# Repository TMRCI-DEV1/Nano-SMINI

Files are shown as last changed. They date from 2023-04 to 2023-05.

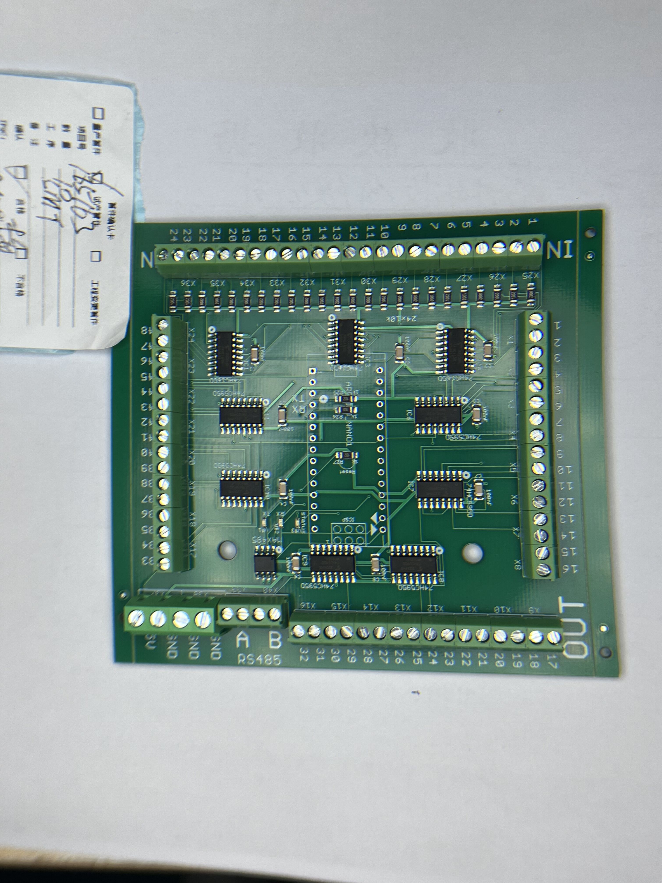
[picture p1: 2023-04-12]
KiCad/3D_Models/185163-1.jpg

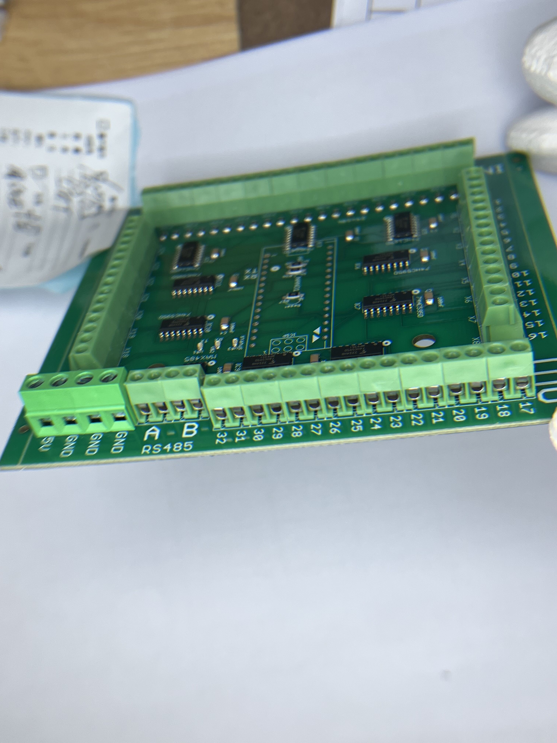
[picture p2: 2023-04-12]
KiCad/3D_Models/185163-2.jpg

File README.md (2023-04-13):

# Nano-SMINI
Arduino Nano-based CMRI SMINI
capture-2023-03-27T16_43_42 577Z

Shield: [][cc-by-sa]

This work is licensed under a
[Creative Commons Attribution-ShareAlike 4.0 International License][cc-by-sa].

[][cc-by-sa]

[cc-by-sa]: http://creativecommons.org/licenses/by-sa/4.0/
[cc-by-sa-image]: https://licensebuttons.net/l/by-sa/4.0/88x31.png
[cc-by-sa-shield]: https://img.shields.io/badge/License-CC%20BY--SA%204.0-lightgrey.svg

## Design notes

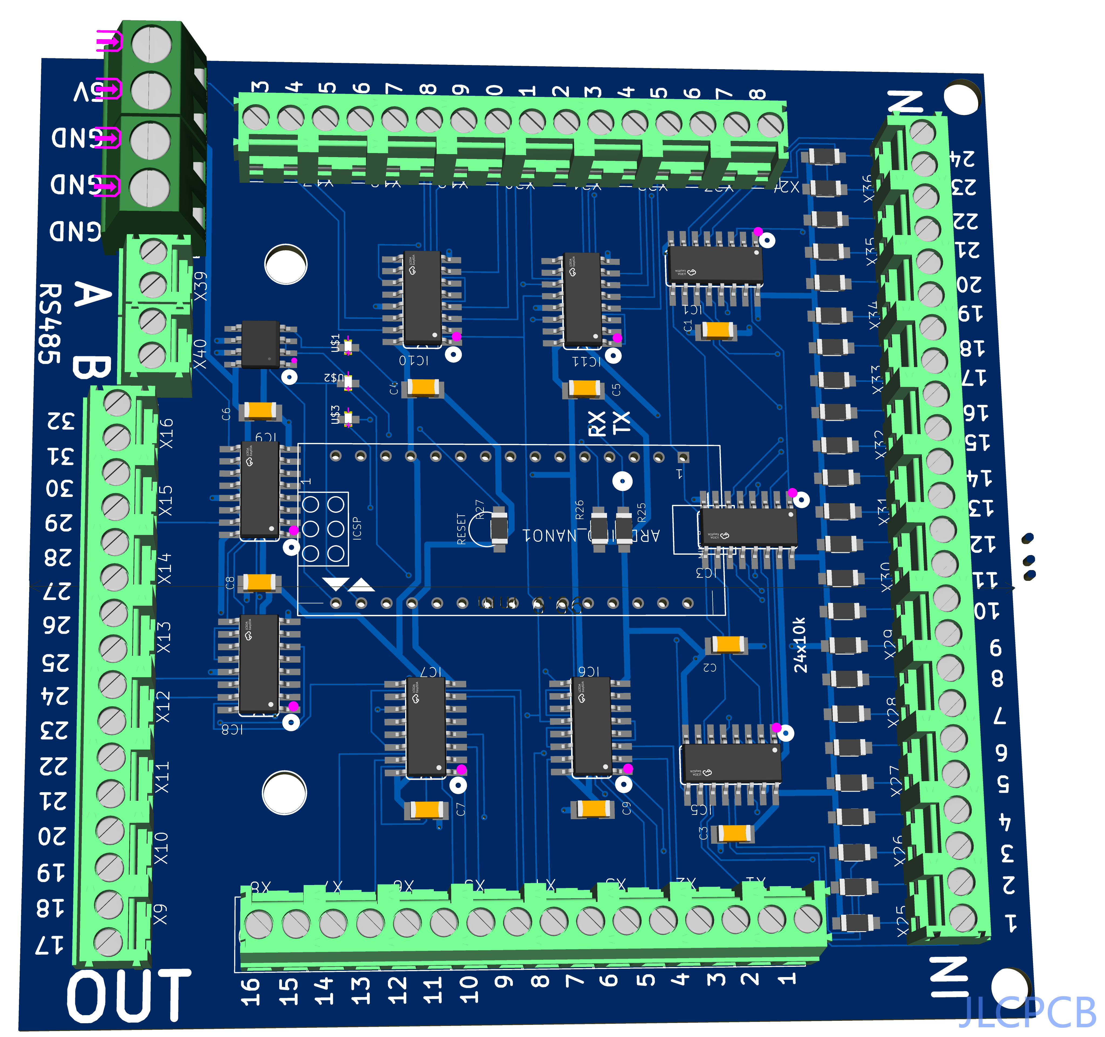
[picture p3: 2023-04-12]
KiCad/3D_Models/capture-2023-03-27T16_43_42.577Z.png

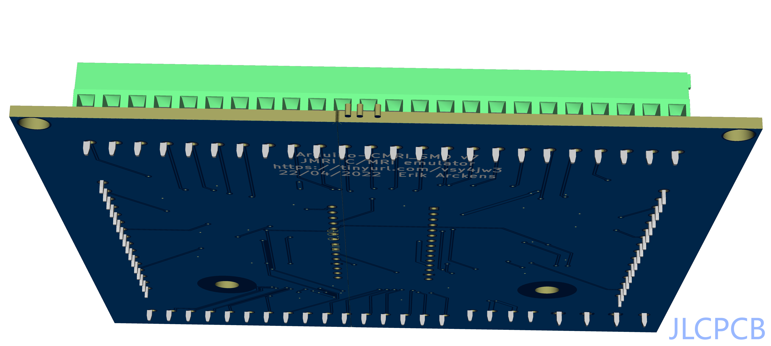
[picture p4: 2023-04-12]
KiCad/3D_Models/capture-2023-03-27T16_43_13.949Z.png

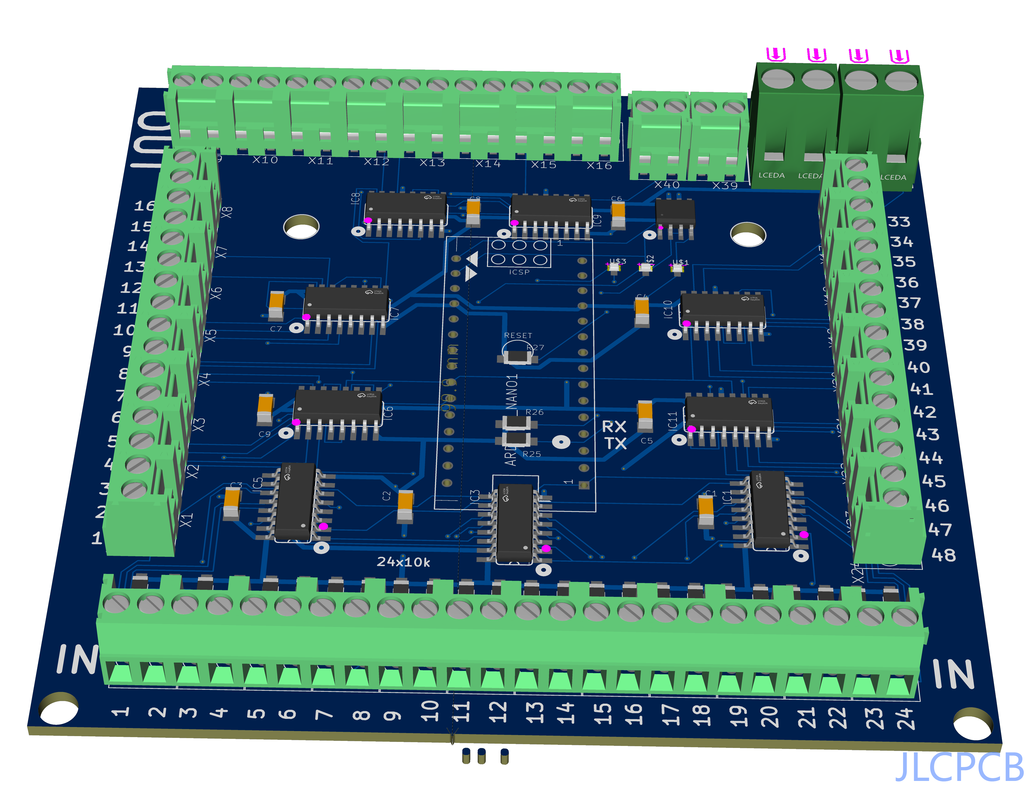
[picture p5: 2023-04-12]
KiCad/3D_Models/capture-2023-03-27T16_43_01.188Z.png

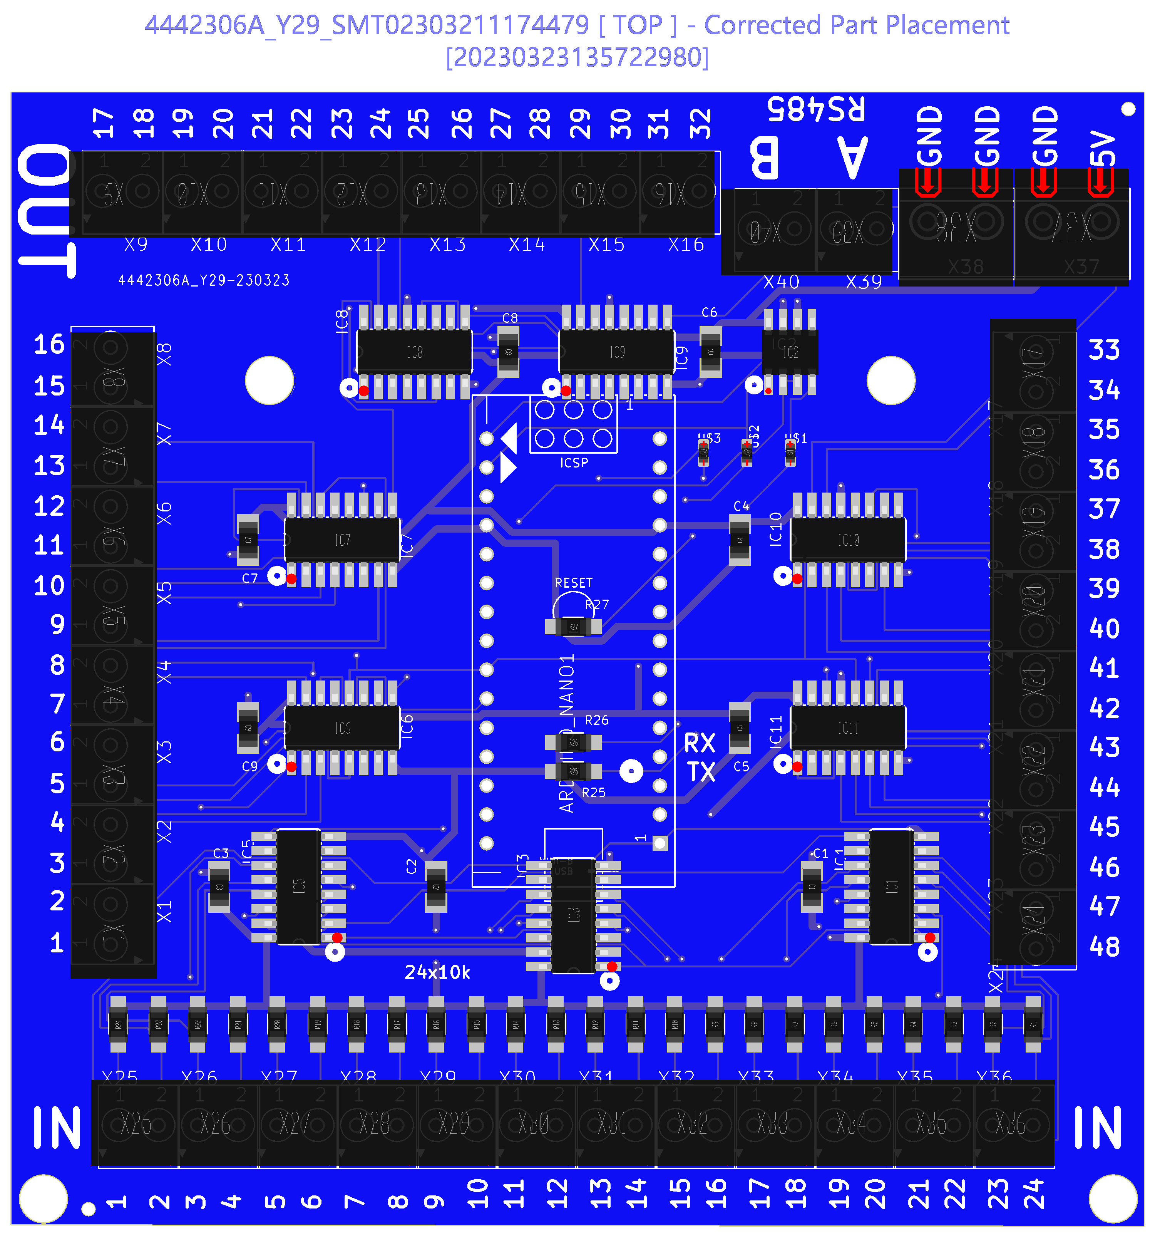
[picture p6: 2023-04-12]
KiCad/3D_Models/Produce_DanZhi.SMT_Snapshot.Top.4442306A_Y29.SMT02303211174479.png

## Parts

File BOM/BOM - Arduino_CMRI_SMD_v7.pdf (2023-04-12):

Designators | Value | Footprint | Manufacturer Part Number | Quantity
C1, C2, C3, C4, C5, C6, C7, C8, C9 | 100nF | 1206 | CL31B104KBCNNNC | 9
R1, R2, R3, R4, R5, R6, R7, R8, R9, R10, R11, R12, R13, R14,
R15, R16, R17, R18, R19, R20, R21, R22, R23, R24 | 10k | 1206 | 1206W4F1002T5E | 24
R25, R26, R27 | 1k | 1206 | 1206W4F1001T5 | 3

X1, X2, X3, X4, X5, X6, X7, X8, X9, X10, X11, X12, X13, X14,
X15, X16, X17, X18, X19, X20, X21, X22, X23, X24, X25, X26,
X27, X28, X29, X30, X31, X32, X33, X34, X35, X36, X39, X40 TERMINAL_7.5X7.3MM_TM | TERMINAL_7.5X7.3MM_TM | KF350-3.5-2P | 38
X37, X38 | TERMINAL_10.16X8.1MM_TM | TERMINAL_10.16X8.1MM_TM WJ128V-5.0-2P | 2
IC6, IC7, IC8, IC9, IC10, IC11 | 74HC595D | SOP16_150MIL | 74HC595D | 6
IC1, IC3, IC5 | 74HC165D, 653 | SOIC16_150MIL | 74HC165D,653 | 3
H1, H2 | MOUNT-HOLE4.1 | 4,1 | 2 | DNP
ARDUINO_NANO1 | ARDUINO_NANO_HEADERS | 15Fx1-254mm | 2 | DNP | 15Fx1-254mm (https://www.electromaker.io/shop/product/254mm-01-15-pin-female-header)
IC2 | MAX485 | SOP8 | MAX485ED | 1
U$1 | TX，CHIPLED_0603, blue | 0603 | LTST-C190TBKT | 1
U$2 | RX，CHIPLED_0603, red | 0603 | LTST-C190KRKT | 1
U$3 | status，CHIPLED_0603, yellow | 0603 | LTST-C190KSKT | 1

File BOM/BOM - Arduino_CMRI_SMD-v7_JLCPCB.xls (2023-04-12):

Comment | Designator | Footprint | JLCPCB Part #
status，CHIPLED_0603,yellow | U$3 | 0603 | C125095
100nF | C1,C2,C3,C4,C5,C6,C7,C8,C9 | 1206 | C24497
MAX485，SO08 | IC2 | SOP8 | C481667
10k | R1,R2,R3,R4,R5,R6,R7,R8,R9,R10,R11,R12,R13,R14,R15,R16,R17,R18,R19,R20,R21,R22,R23,R24 | 1206 | C17902
TERMINAL_7.5X7.3MM_TM | X1,X2,X3,X4,X5,X6,X7,X8,X9,X10,X11,X12,X13,X14,X15,X16,X17,X18,X19,X20,X21,X22,X23,X24,X25,X26,X27,X28,X29,X30,X31,X32,X33,X34,X35,X36,X39,X40 | TERMINAL_7.5X7.3MM_TM | C474892
74HC165D | IC1,IC3,IC5 | SOIC16_150MIL | C5613
RX，CHIPLED_0603,red | U$2 | 0603 | C94869
1k | R25,R26,R27 | 1206 | C4410
TX，CHIPLED_0603，blue | U$1 | 0603 | C125096
74HC595D | IC6,IC7,IC8,IC9,IC10,IC11 | SOP16_150MIL | C431479
TERMINAL_10.16X8.1MM_TM | X37,X38 | TERMINAL_10.16X8.1MM_TM | C8269

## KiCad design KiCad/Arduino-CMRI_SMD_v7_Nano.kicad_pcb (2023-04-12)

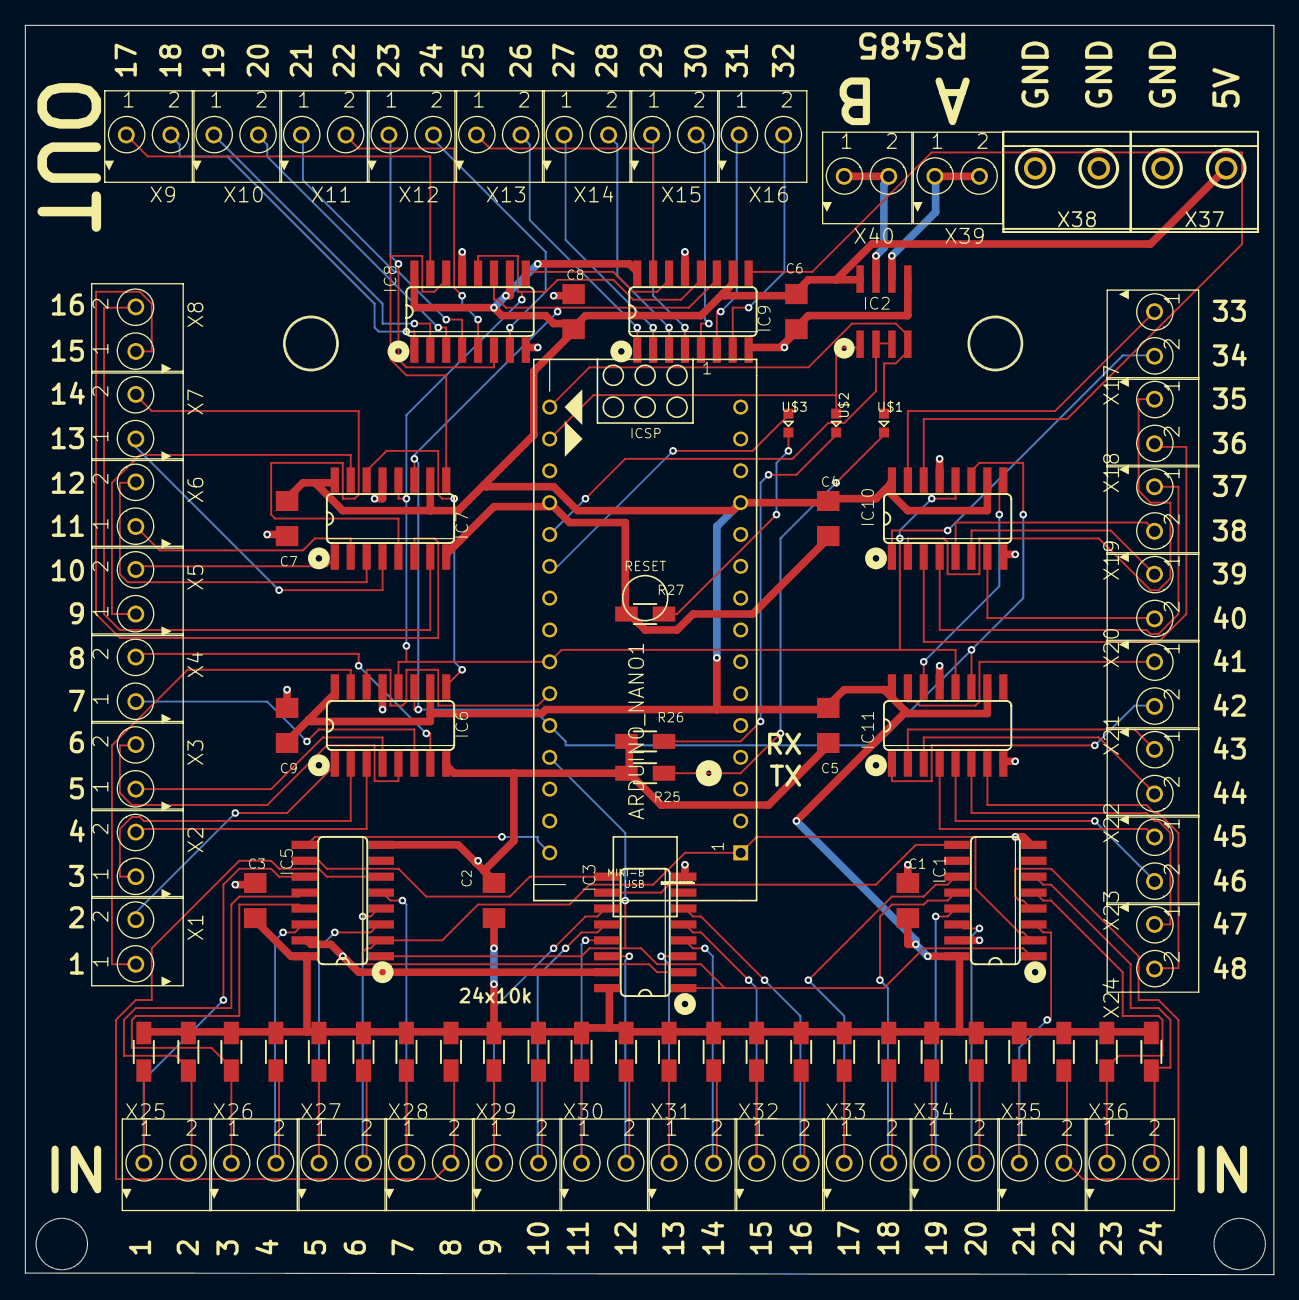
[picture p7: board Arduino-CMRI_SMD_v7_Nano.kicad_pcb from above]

Board: 2 copper layers, 99.6 x 99.7 mm, 92 parts (0 on the bottom side), 96 nets.

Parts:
ARDUINO_NANO1: ARDUINO_NANO
C1, C2, C3, C4, C5, C6, C7, C8, C9: 100nF; 1206
H1, H2: MOUNT-HOLE4.1; 4,1
IC1, IC3, IC5: 74HC165D; SO16
IC2: MAX485; SO08
IC6, IC7, IC8, IC9, IC10, IC11: 74HC595D; SO16
R1, R2, R3, R4, R5, R6, R7, R8, R9, R10, R11, R12, R13, R14, R15, R16, R17, R18, R19, R20, R21, R22, R23, R24: 10k; R1206W
R25, R26, R27: 1k; R1206W
U$1: TX; CHIPLED_0603
U$2: RX; CHIPLED_0603
U$3: status; CHIPLED_0603
X1, X2, X3, X4, X5, X6, X7, X8, X9, X10, X11, X12, X13, X14, X15, X16, X17, X18, X19, X20, X21, X22, X23, X24, X25, X26, X27, X28, X29, X30, X31, X32, X33, X34, X35, X36, X39, X40: TERMINAL_2P_3,5MM_V2; TERMINAL_2P_3,5MM
X37, X38: W237-132

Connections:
A: IC2.6, X39.P$1, X39.P$2
B: IC2.7, X40.P$1, X40.P$2
D2: ARDUINO_NANO1.20, IC2.2, IC2.3
D3: ARDUINO_NANO1.21, U$3.A
D6: ARDUINO_NANO1.24, IC6.12, IC7.12, IC8.12, IC9.12, IC10.12, IC11.12
D7: ARDUINO_NANO1.25, IC6.14
D8: ARDUINO_NANO1.26, IC6.11, IC7.11, IC8.11, IC9.11, IC10.11, IC11.11
D9: ARDUINO_NANO1.27, IC1.1, IC3.1, IC5.1
D12: ARDUINO_NANO1.30, IC5.9
D13: ARDUINO_NANO1.1, IC1.2, IC3.2, IC5.2
GND: ARDUINO_NANO1.14, ARDUINO_NANO1.19, C1.1, C2.1, C3.1, C4.1, C5.1, C6.1, C7.1, C8.1, C9.1, IC1.8, IC1.15, IC2.5, IC3.8, IC3.15, IC5.8, IC5.15, IC6.8, IC6.13, IC7.8, IC7.13, IC8.8, IC8.13, IC9.8, IC9.13, IC10.8, IC10.13, IC11.8, IC11.13, R25.1, R26.1, R27.1, X37.2, X38.1, X38.2
unnamed: IC5.11, R24.1, X25.P$1
unnamed: IC1.9, IC3.10
unnamed: IC5.12, R23.1, X25.P$2
unnamed: IC3.9, IC5.10
unnamed: IC5.13, R22.1, X26.P$1
unnamed: IC6.9, IC7.14
unnamed: IC5.14, R21.1, X26.P$2
unnamed: IC9.9, IC10.14
unnamed: IC5.3, R20.1, X27.P$1
unnamed: IC7.9, IC8.14
unnamed: IC5.4, R19.1, X27.P$2
unnamed: IC10.9, IC11.14
unnamed: IC5.5, R18.1, X28.P$1
unnamed: IC6.15, X1.P$1
unnamed: IC5.6, R17.1, X28.P$2
unnamed: IC6.1, X1.P$2
unnamed: R25.2, U$1.C
unnamed: IC6.2, X2.P$1
unnamed: IC3.11, R16.1, X29.P$1
unnamed: IC6.3, X2.P$2
unnamed: IC3.12, R15.1, X29.P$2
unnamed: IC6.4, X3.P$1
unnamed: IC3.13, R14.1, X30.P$1
unnamed: IC6.5, X3.P$2
unnamed: IC3.14, R13.1, X30.P$2
unnamed: IC6.6, X4.P$1
unnamed: IC3.3, R12.1, X31.P$1
unnamed: IC6.7, X4.P$2
unnamed: IC3.4, R11.1, X31.P$2
unnamed: IC7.15, X5.P$1
unnamed: IC3.5, R10.1, X32.P$1
unnamed: IC7.1, X5.P$2
unnamed: IC3.6, R9.1, X32.P$2
unnamed: IC7.2, X6.P$1
unnamed: IC1.11, R8.1, X33.P$1
unnamed: IC7.3, X6.P$2
unnamed: IC1.12, R7.1, X33.P$2
unnamed: IC7.4, X7.P$1
unnamed: IC1.13, R6.1, X34.P$1
unnamed: IC7.5, X7.P$2
unnamed: IC1.14, R5.1, X34.P$2
unnamed: IC7.6, X8.P$1
unnamed: IC1.3, R4.1, X35.P$1
unnamed: IC7.7, X8.P$2
unnamed: IC1.4, R3.1, X35.P$2
unnamed: IC8.15, X9.P$1
unnamed: IC1.5, R2.1, X36.P$1
unnamed: IC8.1, X9.P$2
unnamed: IC8.2, X10.P$1
unnamed: IC8.3, X10.P$2
unnamed: IC8.9, IC9.14
unnamed: IC8.4, X11.P$1
unnamed: IC8.5, X11.P$2
unnamed: R26.2, U$2.C
unnamed: IC1.6, R1.1, X36.P$2
unnamed: R27.2, U$3.C
unnamed: IC8.6, X12.P$1
unnamed: IC8.7, X12.P$2
unnamed: IC9.15, X13.P$1
unnamed: IC9.1, X13.P$2
unnamed: IC9.2, X14.P$1
unnamed: IC9.3, X14.P$2
unnamed: IC9.4, X15.P$1
unnamed: IC9.5, X15.P$2
unnamed: IC9.6, X16.P$1
unnamed: IC9.7, X16.P$2
unnamed: IC10.15, X17.P$1
unnamed: IC10.1, X17.P$2
unnamed: IC10.2, X18.P$1
unnamed: IC10.3, X18.P$2
unnamed: IC10.4, X19.P$1
unnamed: IC10.5, X19.P$2
unnamed: IC10.6, X20.P$1
unnamed: IC10.7, X20.P$2
unnamed: IC11.15, X21.P$1
unnamed: IC11.1, X21.P$2
unnamed: IC11.2, X22.P$1
unnamed: IC11.3, X22.P$2
unnamed: IC11.4, X23.P$1
unnamed: IC11.5, X23.P$2
unnamed: IC11.6, X24.P$1
unnamed: IC11.7, X24.P$2
RX: ARDUINO_NANO1.17, IC2.1, U$2.A
TX: ARDUINO_NANO1.16, IC2.4, U$1.A
VCC: ARDUINO_NANO1.12, C1.2, C2.2, C3.2, C4.2, C5.2, C6.2, C7.2, C8.2, C9.2, IC1.16, IC2.8, IC3.16, IC5.16, IC6.10, IC6.16, IC7.10, IC7.16, IC8.10, IC8.16, IC9.10, IC9.16, IC10.10, IC10.16, IC11.10, IC11.16, R1.2, R2.2, R3.2, R4.2, R5.2, R6.2, R7.2, R8.2, R9.2, R10.2, R11.2, R12.2, R13.2, R14.2, R15.2, R16.2, R17.2, R18.2, R19.2, R20.2, R21.2, R22.2, R23.2, R24.2, X37.1

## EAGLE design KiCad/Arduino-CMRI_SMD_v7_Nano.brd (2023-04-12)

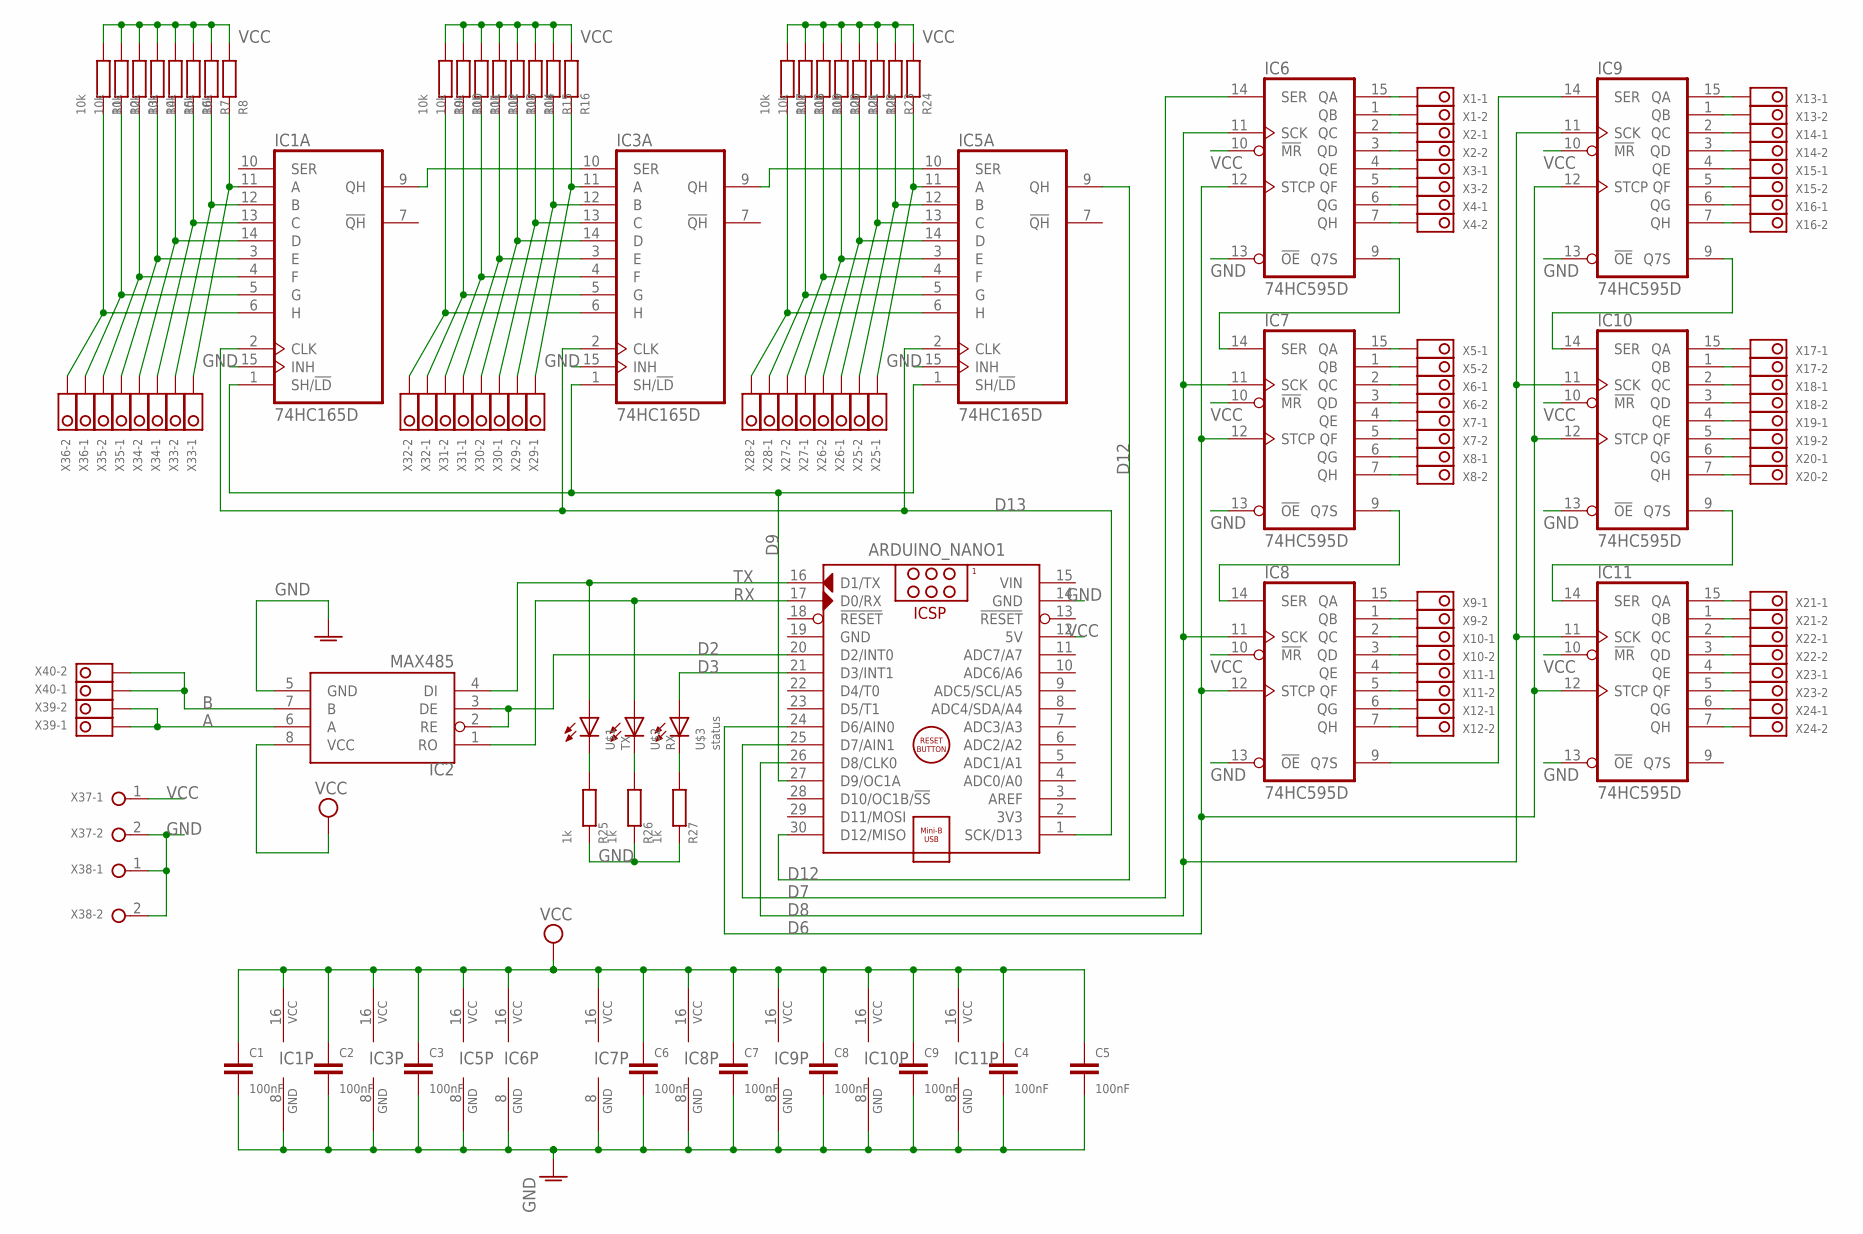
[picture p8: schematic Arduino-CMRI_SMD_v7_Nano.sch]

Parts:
ARDUINO_NANO1: ARDUINO_NANO
C1, C2, C3, C4, C5, C6, C7, C8, C9: 100nF; 1206
IC1, IC3, IC5: 74HC165D; SO16
IC2: MAX485; SO08
IC6, IC7, IC8, IC9, IC10, IC11: 74HC595D; SO16
R1, R2, R3, R4, R5, R6, R7, R8, R9, R10, R11, R12, R13, R14, R15, R16, R17, R18, R19, R20, R21, R22, R23, R24: 10k; R1206W
R25, R26, R27: 1k; R1206W
U$1: TX; CHIPLED_0603
U$2: RX; CHIPLED_0603
U$3: status; CHIPLED_0603
X1, X2, X3, X4, X5, X6, X7, X8, X9, X10, X11, X12, X13, X14, X15, X16, X17, X18, X19, X20, X21, X22, X23, X24, X25, X26, X27, X28, X29, X30, X31, X32, X33, X34, X35, X36, X39, X40: TERMINAL_2P_3,5MM_V2; TERMINAL_2P_3,5MM
X37, X38: TERMINAL-5MM-2POLE; W237-132

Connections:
A: IC2.6 (A), X39.P$1, X39.P$2
B: IC2.7 (B), X40.P$1, X40.P$2
D2: ARDUINO_NANO1.20 (D2/INT0), IC2.2 (RE), IC2.3 (DE)
D3: ARDUINO_NANO1.21 (D3/INT1), U$3.A
D6: ARDUINO_NANO1.24 (D6/AIN0), IC6.12 (STCP), IC7.12 (STCP), IC8.12 (STCP), IC9.12 (STCP), IC10.12 (STCP), IC11.12 (STCP)
D7: ARDUINO_NANO1.25 (D7/AIN1), IC6.14 (SER)
D8: ARDUINO_NANO1.26 (D8/CLK0), IC6.11 (SCK), IC7.11 (SCK), IC8.11 (SCK), IC9.11 (SCK), IC10.11 (SCK), IC11.11 (SCK)
D9: ARDUINO_NANO1.27 (D9/OC1A), IC1.1 (SH/!LD), IC3.1 (SH/!LD), IC5.1 (SH/!LD)
D12: ARDUINO_NANO1.30 (D12/MISO), IC5.9 (QH)
D13: ARDUINO_NANO1.1 (SCK/D13), IC1.2 (CLK), IC3.2 (CLK), IC5.2 (CLK)
GND: ARDUINO_NANO1.14 (GND), ARDUINO_NANO1.19 (GND), C1.1, C2.1, C3.1, C4.1, C5.1, C6.1, C7.1, C8.1, C9.1, IC1.8 (GND), IC1.15 (INH), IC2.5 (GND), IC3.8 (GND), IC3.15 (INH), IC5.8 (GND), IC5.15 (INH), IC6.8 (GND), IC6.13 (!OE), IC7.8 (GND), IC7.13 (!OE), IC8.8 (GND), IC8.13 (!OE), IC9.8 (GND), IC9.13 (!OE), IC10.8 (GND), IC10.13 (!OE), IC11.8 (GND), IC11.13 (!OE), R25.1, R26.1, R27.1, X37.2, X38.1, X38.2
unnamed: IC5.11 (A), R24.1, X25.P$1
unnamed: IC1.9 (QH), IC3.10 (SER)
unnamed: IC5.12 (B), R23.1, X25.P$2
unnamed: IC3.9 (QH), IC5.10 (SER)
unnamed: IC5.13 (C), R22.1, X26.P$1
unnamed: IC6.9 (Q7S), IC7.14 (SER)
unnamed: IC5.14 (D), R21.1, X26.P$2
unnamed: IC9.9 (Q7S), IC10.14 (SER)
unnamed: IC5.3 (E), R20.1, X27.P$1
unnamed: IC7.9 (Q7S), IC8.14 (SER)
unnamed: IC5.4 (F), R19.1, X27.P$2
unnamed: IC10.9 (Q7S), IC11.14 (SER)
unnamed: IC5.5 (G), R18.1, X28.P$1
unnamed: IC6.15 (QA), X1.P$1
unnamed: IC5.6 (H), R17.1, X28.P$2
unnamed: IC6.1 (QB), X1.P$2
unnamed: R25.2, U$1.C
unnamed: IC6.2 (QC), X2.P$1
unnamed: IC3.11 (A), R16.1, X29.P$1
unnamed: IC6.3 (QD), X2.P$2
unnamed: IC3.12 (B), R15.1, X29.P$2
unnamed: IC6.4 (QE), X3.P$1
unnamed: IC3.13 (C), R14.1, X30.P$1
unnamed: IC6.5 (QF), X3.P$2
unnamed: IC3.14 (D), R13.1, X30.P$2
unnamed: IC6.6 (QG), X4.P$1
unnamed: IC3.3 (E), R12.1, X31.P$1
unnamed: IC6.7 (QH), X4.P$2
unnamed: IC3.4 (F), R11.1, X31.P$2
unnamed: IC7.15 (QA), X5.P$1
unnamed: IC3.5 (G), R10.1, X32.P$1
unnamed: IC7.1 (QB), X5.P$2
unnamed: IC3.6 (H), R9.1, X32.P$2
unnamed: IC7.2 (QC), X6.P$1
unnamed: IC1.11 (A), R8.1, X33.P$1
unnamed: IC7.3 (QD), X6.P$2
unnamed: IC1.12 (B), R7.1, X33.P$2
unnamed: IC7.4 (QE), X7.P$1
unnamed: IC1.13 (C), R6.1, X34.P$1
unnamed: IC7.5 (QF), X7.P$2
unnamed: IC1.14 (D), R5.1, X34.P$2
unnamed: IC7.6 (QG), X8.P$1
unnamed: IC1.3 (E), R4.1, X35.P$1
unnamed: IC7.7 (QH), X8.P$2
unnamed: IC1.4 (F), R3.1, X35.P$2
unnamed: IC8.15 (QA), X9.P$1
unnamed: IC1.5 (G), R2.1, X36.P$1
unnamed: IC8.1 (QB), X9.P$2
unnamed: IC8.2 (QC), X10.P$1
unnamed: IC8.3 (QD), X10.P$2
unnamed: IC8.9 (Q7S), IC9.14 (SER)
unnamed: IC8.4 (QE), X11.P$1
unnamed: IC8.5 (QF), X11.P$2
unnamed: R26.2, U$2.C
unnamed: IC1.6 (H), R1.1, X36.P$2
unnamed: R27.2, U$3.C
unnamed: IC8.6 (QG), X12.P$1
unnamed: IC8.7 (QH), X12.P$2
unnamed: IC9.15 (QA), X13.P$1
unnamed: IC9.1 (QB), X13.P$2
unnamed: IC9.2 (QC), X14.P$1
unnamed: IC9.3 (QD), X14.P$2
unnamed: IC9.4 (QE), X15.P$1
unnamed: IC9.5 (QF), X15.P$2
unnamed: IC9.6 (QG), X16.P$1
unnamed: IC9.7 (QH), X16.P$2
unnamed: IC10.15 (QA), X17.P$1
unnamed: IC10.1 (QB), X17.P$2
unnamed: IC10.2 (QC), X18.P$1
unnamed: IC10.3 (QD), X18.P$2
unnamed: IC10.4 (QE), X19.P$1
unnamed: IC10.5 (QF), X19.P$2
unnamed: IC10.6 (QG), X20.P$1
unnamed: IC10.7 (QH), X20.P$2
unnamed: IC11.15 (QA), X21.P$1
unnamed: IC11.1 (QB), X21.P$2
unnamed: IC11.2 (QC), X22.P$1
unnamed: IC11.3 (QD), X22.P$2
unnamed: IC11.4 (QE), X23.P$1
unnamed: IC11.5 (QF), X23.P$2
unnamed: IC11.6 (QG), X24.P$1
unnamed: IC11.7 (QH), X24.P$2
RX: ARDUINO_NANO1.17 (D0/RX), IC2.1 (RO), U$2.A
TX: ARDUINO_NANO1.16 (D1/TX), IC2.4 (DI), U$1.A
VCC: ARDUINO_NANO1.12 (5V), C1.2, C2.2, C3.2, C4.2, C5.2, C6.2, C7.2, C8.2, C9.2, IC1.16 (VCC), IC2.8 (VCC), IC3.16 (VCC), IC5.16 (VCC), IC6.10 (!MR), IC6.16 (VCC), IC7.10 (!MR), IC7.16 (VCC), IC8.10 (!MR), IC8.16 (VCC), IC9.10 (!MR), IC9.16 (VCC), IC10.10 (!MR), IC10.16 (VCC), IC11.10 (!MR), IC11.16 (VCC), R1.2, R2.2, R3.2, R4.2, R5.2, R6.2, R7.2, R8.2, R9.2, R10.2, R11.2, R12.2, R13.2, R14.2, R15.2, R16.2, R17.2, R18.2, R19.2, R20.2, R21.2, R22.2, R23.2, R24.2, X37.1
VIN: ARDUINO_NANO1.15 (VIN)

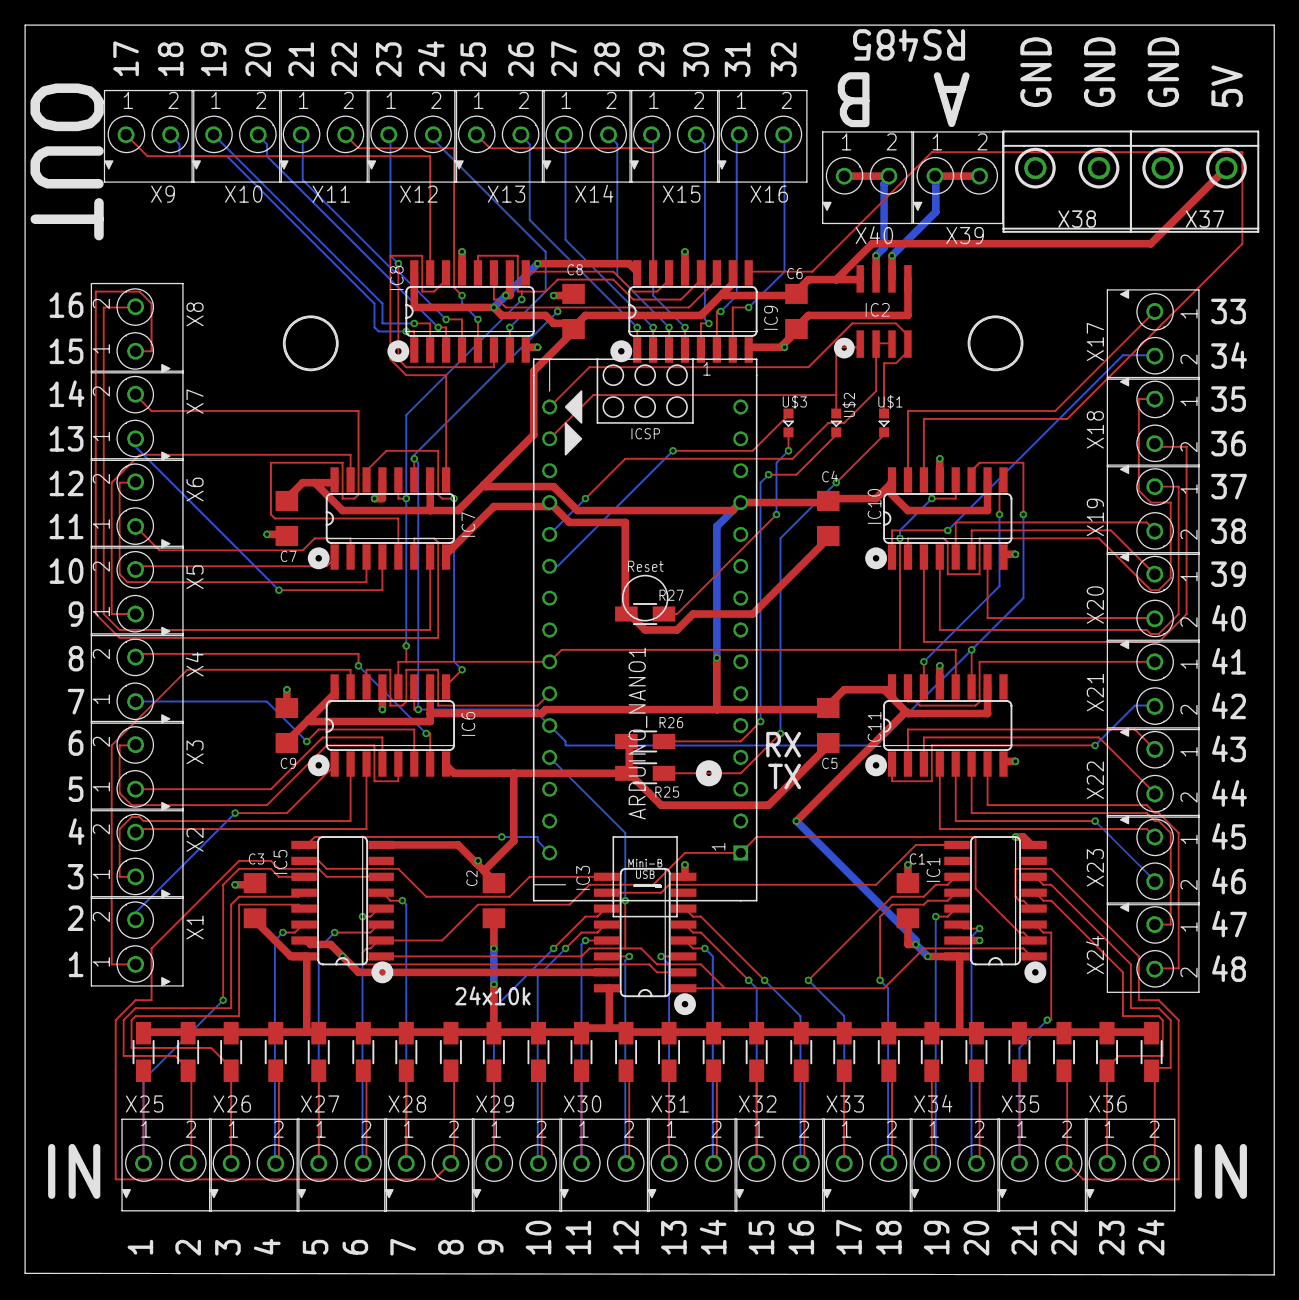
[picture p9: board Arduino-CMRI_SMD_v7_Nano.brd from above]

Board: 2 copper layers, 99.6 x 99.7 mm, 92 parts (0 on the bottom side), 96 nets.

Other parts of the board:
H1, H2: MOUNT-HOLE4.1; 4,1

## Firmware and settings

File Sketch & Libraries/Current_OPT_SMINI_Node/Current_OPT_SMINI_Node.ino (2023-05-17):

/*
  Project: Arduino Nano-based CMRI SMINI Node (48 outputs & 24 inputs)
  Author: Thomas Seitz (thomas.seitz@tmrci.org)
  Version: 1.0.2
  Date: 2023-05-17
  Description: A sketch for an Arduino Nano-based CMRI SMINI Node board using RS-485
*/

// Import required libraries
#include <Auto485.h>                                // Library for RS485 communication
#include <CMRI.h>                                   // Library for CMRI communication
#include <SPI.h>                                    // Library for SPI communication

const byte CMRI_ADDR = 4;                           // Define CMRI node address
const byte DE_PIN = 2;                              // Define RS485 DE and RE pins on Arduino
#define NOP __asm__ __volatile__("nop")             // "nop" assembly instruction macro

// Define pins for 74HC165
const byte LATCH_165 = 9;

// Define pins for 74HC595
const byte LATCH_595 = 6;
const byte DATA_595 = 7;
const byte CLOCK_595 = 8;

Auto485 bus(DE_PIN);                                // Initialize RS485 bus transceiver
CMRI cmri(CMRI_ADDR, 24, 48, bus);                  // sets up an SMINI. SMINI = 24 inputs, 48 outputs

byte last_input_state[3];                           // Define variable to store the previous state of inputs
byte last_output_state[6];                          // Define variable to store the previous state of outputs

void setup() {
  // Open the RS485 bus at 19200bps
  bus.begin(19200, SERIAL_8N2);

  // 74HC165 setup
  pinMode(LATCH_165, OUTPUT);
  digitalWrite(LATCH_165, HIGH);                    // Initialize Latch High
  SPI.begin ();                                     // Start SPI communication to control 74HC165

  // 74HC595 setup
  pinMode(LATCH_595, OUTPUT);
  pinMode(DATA_595, OUTPUT);
  pinMode(CLOCK_595, OUTPUT);

  // Initialize last_input_state array with current input state
  digitalWrite(LATCH_165, LOW);                     // Pulse the parallel load latch
  NOP;                                              // Wait while data loads
  NOP;
  digitalWrite(LATCH_165, HIGH);
  last_input_state[0] = ~(SPI.transfer(0));
  last_input_state[1] = ~(SPI.transfer(0));
  last_input_state[2] = ~(SPI.transfer(0));
}

void loop() {
  // Step 1: Process incoming messages on the CMRI bus
  cmri.process();

  // Step 2: Update the output shift registers if the output state has changed
  byte currentOutputState[6];
  for (int i = 0; i < 6; i++) {
    currentOutputState[i] = cmri.get_byte(i);
  }

  if (memcmp(last_output_state, currentOutputState, 6) != 0) {
    memcpy(last_output_state, currentOutputState, 6);

    digitalWrite(LATCH_595, LOW);                     // Start by setting Latch Low
    for (int i = 5; i >= 0; i--) {
      shiftOut(DATA_595, CLOCK_595, MSBFIRST, ~currentOutputState[i]); // Send the ith byte
    }
    digitalWrite(LATCH_595, HIGH);                    // Set the Latch High to update the Data
  }

  // Step 3: Read the current state of the input pins
  digitalWrite(LATCH_165, LOW);                     // pulse the parallel load latch
  NOP;
  NOP;
  digitalWrite(LATCH_165, HIGH);
  byte currentInputState[3];
  currentInputState[0] = ~(SPI.transfer(0));
  currentInputState[1] = ~(SPI.transfer(0));
  currentInputState[2] = ~(SPI.transfer(0));

  // Step 4: If the input state has changed, update the CMRI input bytes
  if (memcmp(currentInputState, last_input_state, 3) != 0) {
    memcpy(last_input_state, currentInputState, 3);
    for (int i = 0; i < 3; i++) {
      cmri.set_byte(i, currentInputState[i]);
    }
  }
}

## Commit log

2023-04-12 Added full project
    [Arduino-CMRI_SMD_v7_Nano-B_Cu.gbl, Arduino-CMRI_SMD_v7_Nano-B_Mask.gbs, Arduino-CMRI_SMD_v7_Nano-B_Paste.gbp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]
2023-05-17 Update Current_OPT_SMINI_Node.ino
    Latest version
2023-05-17 Update Current_OPT_SMINI_Node.ino
    Added header

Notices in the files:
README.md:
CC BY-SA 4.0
